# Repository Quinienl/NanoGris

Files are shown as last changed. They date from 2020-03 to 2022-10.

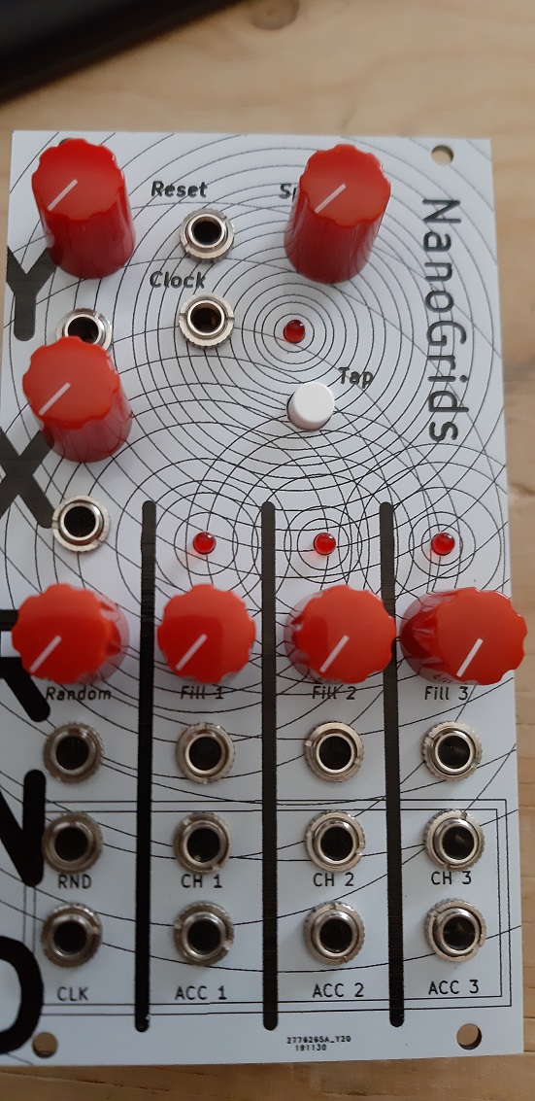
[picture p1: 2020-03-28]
Images/red.jpg

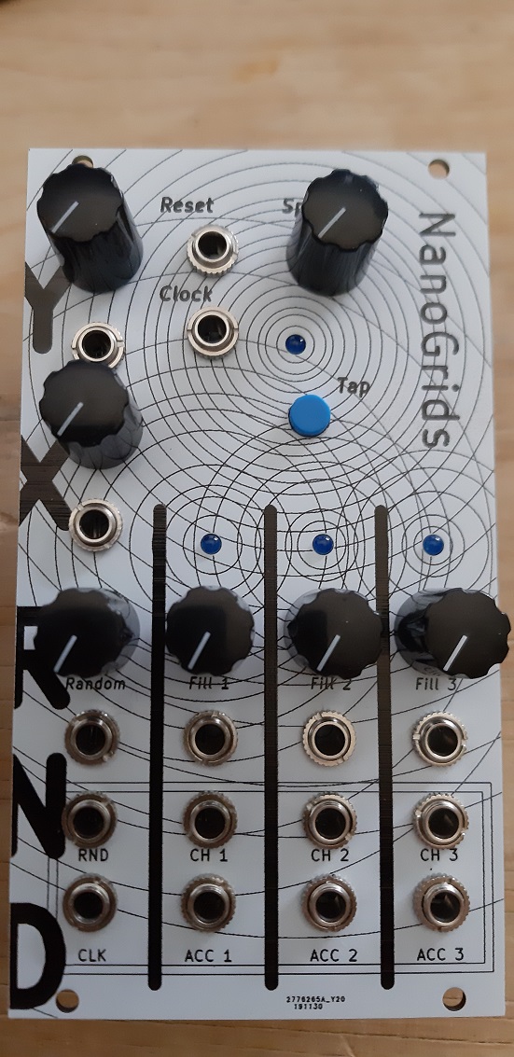
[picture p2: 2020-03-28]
Images/blue.jpg

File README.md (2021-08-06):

# NanoGrids
### Arduino Nano version of Mutable Instruments Grids

Made this version  with Thru Hole parts and a Arduino Nano.
Schematics are heavely based on Mutable Instruments schematics. This is not a Mutable Instuments product.

_Note: panel hole for button might be a bit to big or small (depends if you use buttoncaps)_

I made this for my own and would like to share it with you. I'm doing this as a hobby so expect support to be like that to ;)
Everything at your own risk..

Some info on my website that might help

https://www.quinie.nl/category/diy/nanogris/

https://www.quinie.nl/nanogris-gallery/

If you don not want to order boards yourself please check out my shop.
https://www.quinie.nl/shop/

hex file for uploading here
https://www.quinie.nl/nanogris-the-hex-file/

Update: 6-8-2021
I updated the name of the module. The current version is 0.041

Older boards will have the same function. Did add some better ground planes. Some silkscreen additions to make build easier and changed the footprint of the potentiometer for better fit.

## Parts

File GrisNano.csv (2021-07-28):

Comment | Designator | Footprint | LCSC
Arduino_Nano_v2.x | A1 | Module:Arduino_Nano
10nf | C1,C2,C5,C6,C8,C9,C12 | Capacitor_THT:C_Disc_D5.0mm_W2.5mm_P2.50mm
10uf | C14,C13 | Capacitor_THT:CP_Radial_D5.0mm_P2.50mm
0.47uf | C15,C11 | Capacitor_THT:CP_Radial_D5.0mm_P2.50mm
100nf | C4,C3,C7,C10,C16 | Capacitor_THT:C_Disc_D5.0mm_W2.5mm_P2.50mm
CH1 | CH1 | Connector_Audio:Jack_3.5mm_QingPu_WQP-PJ398SM_Vertical_CircularHoles
CH1_ACC | CH1_AC1 | Connector_Audio:Jack_3.5mm_QingPu_WQP-PJ398SM_Vertical_CircularHoles
CV_CH1 | CH1_FILL1 | Connector_Audio:Jack_3.5mm_QingPu_WQP-PJ398SM_Vertical_CircularHoles
CH2 | CH2 | Connector_Audio:Jack_3.5mm_QingPu_WQP-PJ398SM_Vertical_CircularHoles
CH2_ACC | CH2_AC1 | Connector_Audio:Jack_3.5mm_QingPu_WQP-PJ398SM_Vertical_CircularHoles
CV_CH2 | CH2_FILL1 | Connector_Audio:Jack_3.5mm_QingPu_WQP-PJ398SM_Vertical_CircularHoles
CH3 | CH3 | Connector_Audio:Jack_3.5mm_QingPu_WQP-PJ398SM_Vertical_CircularHoles
CH3_ACC | CH3_AC1 | Connector_Audio:Jack_3.5mm_QingPu_WQP-PJ398SM_Vertical_CircularHoles
CV_CH3 | CH3_FILL1 | Connector_Audio:Jack_3.5mm_QingPu_WQP-PJ398SM_Vertical_CircularHoles
ClockOutput | CLK1 | Connector_Audio:Jack_3.5mm_QingPu_WQP-PJ398SM_Vertical_CircularHoles
CV_CLOCK | CLOCK1 | Connector_Audio:Jack_3.5mm_QingPu_WQP-PJ398SM_Vertical_CircularHoles
CH1 | D1 | LED_THT:LED_D3.0mm
CH2 | D2 | LED_THT:LED_D3.0mm
CH3 | D3 | LED_THT:LED_D3.0mm
CLK | D4 | LED_THT:LED_D3.0mm
1n4148 | D6,D5 | Diode_THT:D_DO-34_SOD68_P7.62mm_Horizontal
Fiducial | FID1 | Symbol:OSHW-Logo2_7.3x6mm_SilkScreen
Fiducial | FID2 | Symbol:OSHW-Logo2_14.6x12mm_SilkScreen
MountingHole | H1,H2 | MountingHole:MountingHole_3.2mm_M3
Conn_01x12 | J10 | Connector_PinSocket_2.54mm:PinSocket_1x12_P2.54mm_Vertical
Conn_01x12 | J11 | Connector_PinHeader_2.54mm:PinHeader_1x12_P2.54mm_Vertical
Conn_02x05_Odd_Even | J12 | Connector_PinHeader_2.54mm:PinHeader_2x05_P2.54mm_Vertical
Conn_01x10 | J14,J15 | Connector_PinHeader_2.54mm:PinHeader_1x10_P2.54mm_Vertical
Conn_01x03 | J16 | Connector_PinHeader_2.54mm:PinHeader_1x03_P2.54mm_Vertical
Conn_01x10 | J7,J13 | Connector_PinSocket_2.54mm:PinSocket_1x10_P2.54mm_Vertical
10k | P_TEMPO1,P_CH2,P_CH1,P_X1,P_CH3,P_RND1,P_Y1 | Potentiometer_THT:Potentiometer_Alpha_RD901F-40-00D_Single_Vertical
2N3904 | Q2,Q1 | Package_TO_SOT_THT:TO-92_Wide
100k | R1,R2,R3,R7,R4,R5,R6,R8,R9,R10,R11,R15,R12,R13,R14,R16,R17,R18,R19,R23,R20,R21,R22,R24,R43,R44,R45,R42,R41,R40,R31 | Resistor_THT:R_Axial_DIN0204_L3.6mm_D1.6mm_P7.62mm_Horizontal
100r | R25,R28,R27,R26 | Resistor_THT:R_Axial_DIN0207_L6.3mm_D2.5mm_P7.62mm_Horizontal
10r | R30,R29 | Resistor_THT:R_Axial_DIN0204_L3.6mm_D1.6mm_P7.62mm_Horizontal
1k | R39,R38,R37,R36,R35,R34,R33,R32 | Resistor_THT:R_Axial_DIN0204_L3.6mm_D1.6mm_P7.62mm_Horizontal
CV_RESET | RESET1 | Connector_Audio:Jack_3.5mm_QingPu_WQP-PJ398SM_Vertical_CircularHoles
SW_Push | RESET2 | Button_Switch_THT:SW_PUSH_6mm
RandomGate | RND1 | Connector_Audio:Jack_3.5mm_QingPu_WQP-PJ398SM_Vertical_CircularHoles
CV_RND | RND2 | Connector_Audio:Jack_3.5mm_QingPu_WQP-PJ398SM_Vertical_CircularHoles
MCP6002_1 | U1,U2,U3 | Package_DIP:DIP-8_W7.62mm
L7805 | U4 | Package_TO_SOT_THT:TO-220-3_Vertical
LM4040LP-5 | U5 | Package_TO_SOT_THT:TO-92_Wide
74HC595 | U6 | Package_DIP:DIP-16_W7.62mm
CV_X | X1 | Connector_Audio:Jack_3.5mm_QingPu_WQP-PJ398SM_Vertical_CircularHoles
CV_Y | Y1 | Connector_Audio:Jack_3.5mm_QingPu_WQP-PJ398SM_Vertical_CircularHoles

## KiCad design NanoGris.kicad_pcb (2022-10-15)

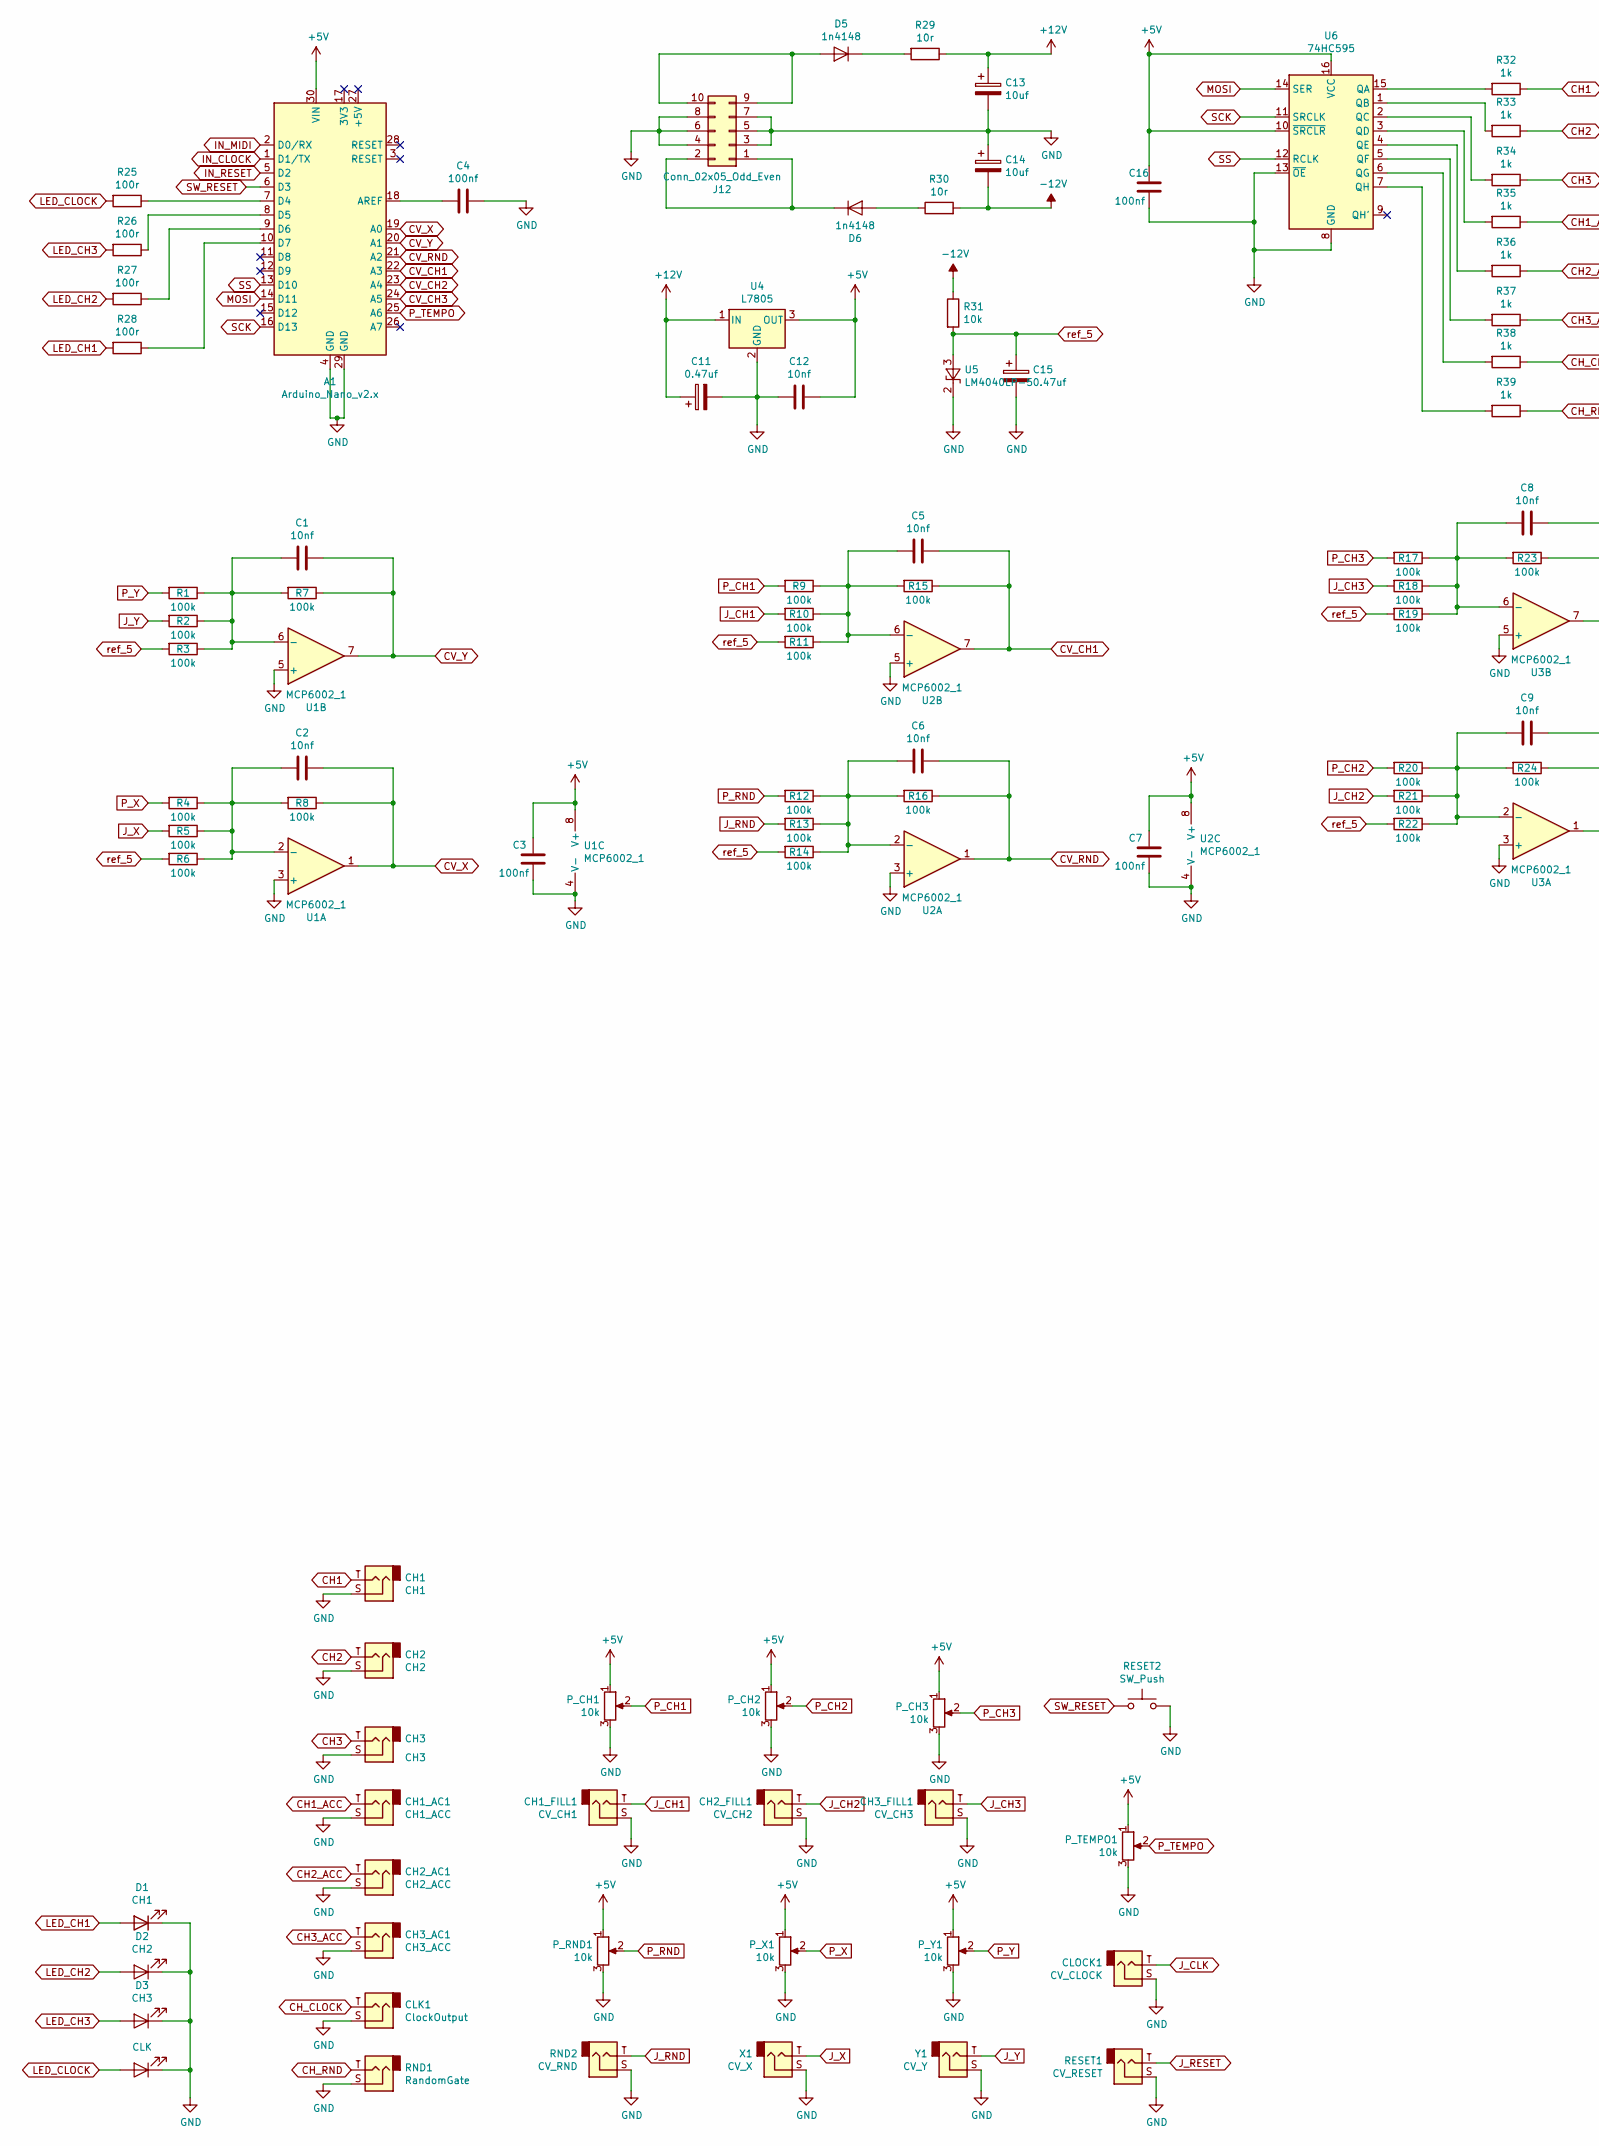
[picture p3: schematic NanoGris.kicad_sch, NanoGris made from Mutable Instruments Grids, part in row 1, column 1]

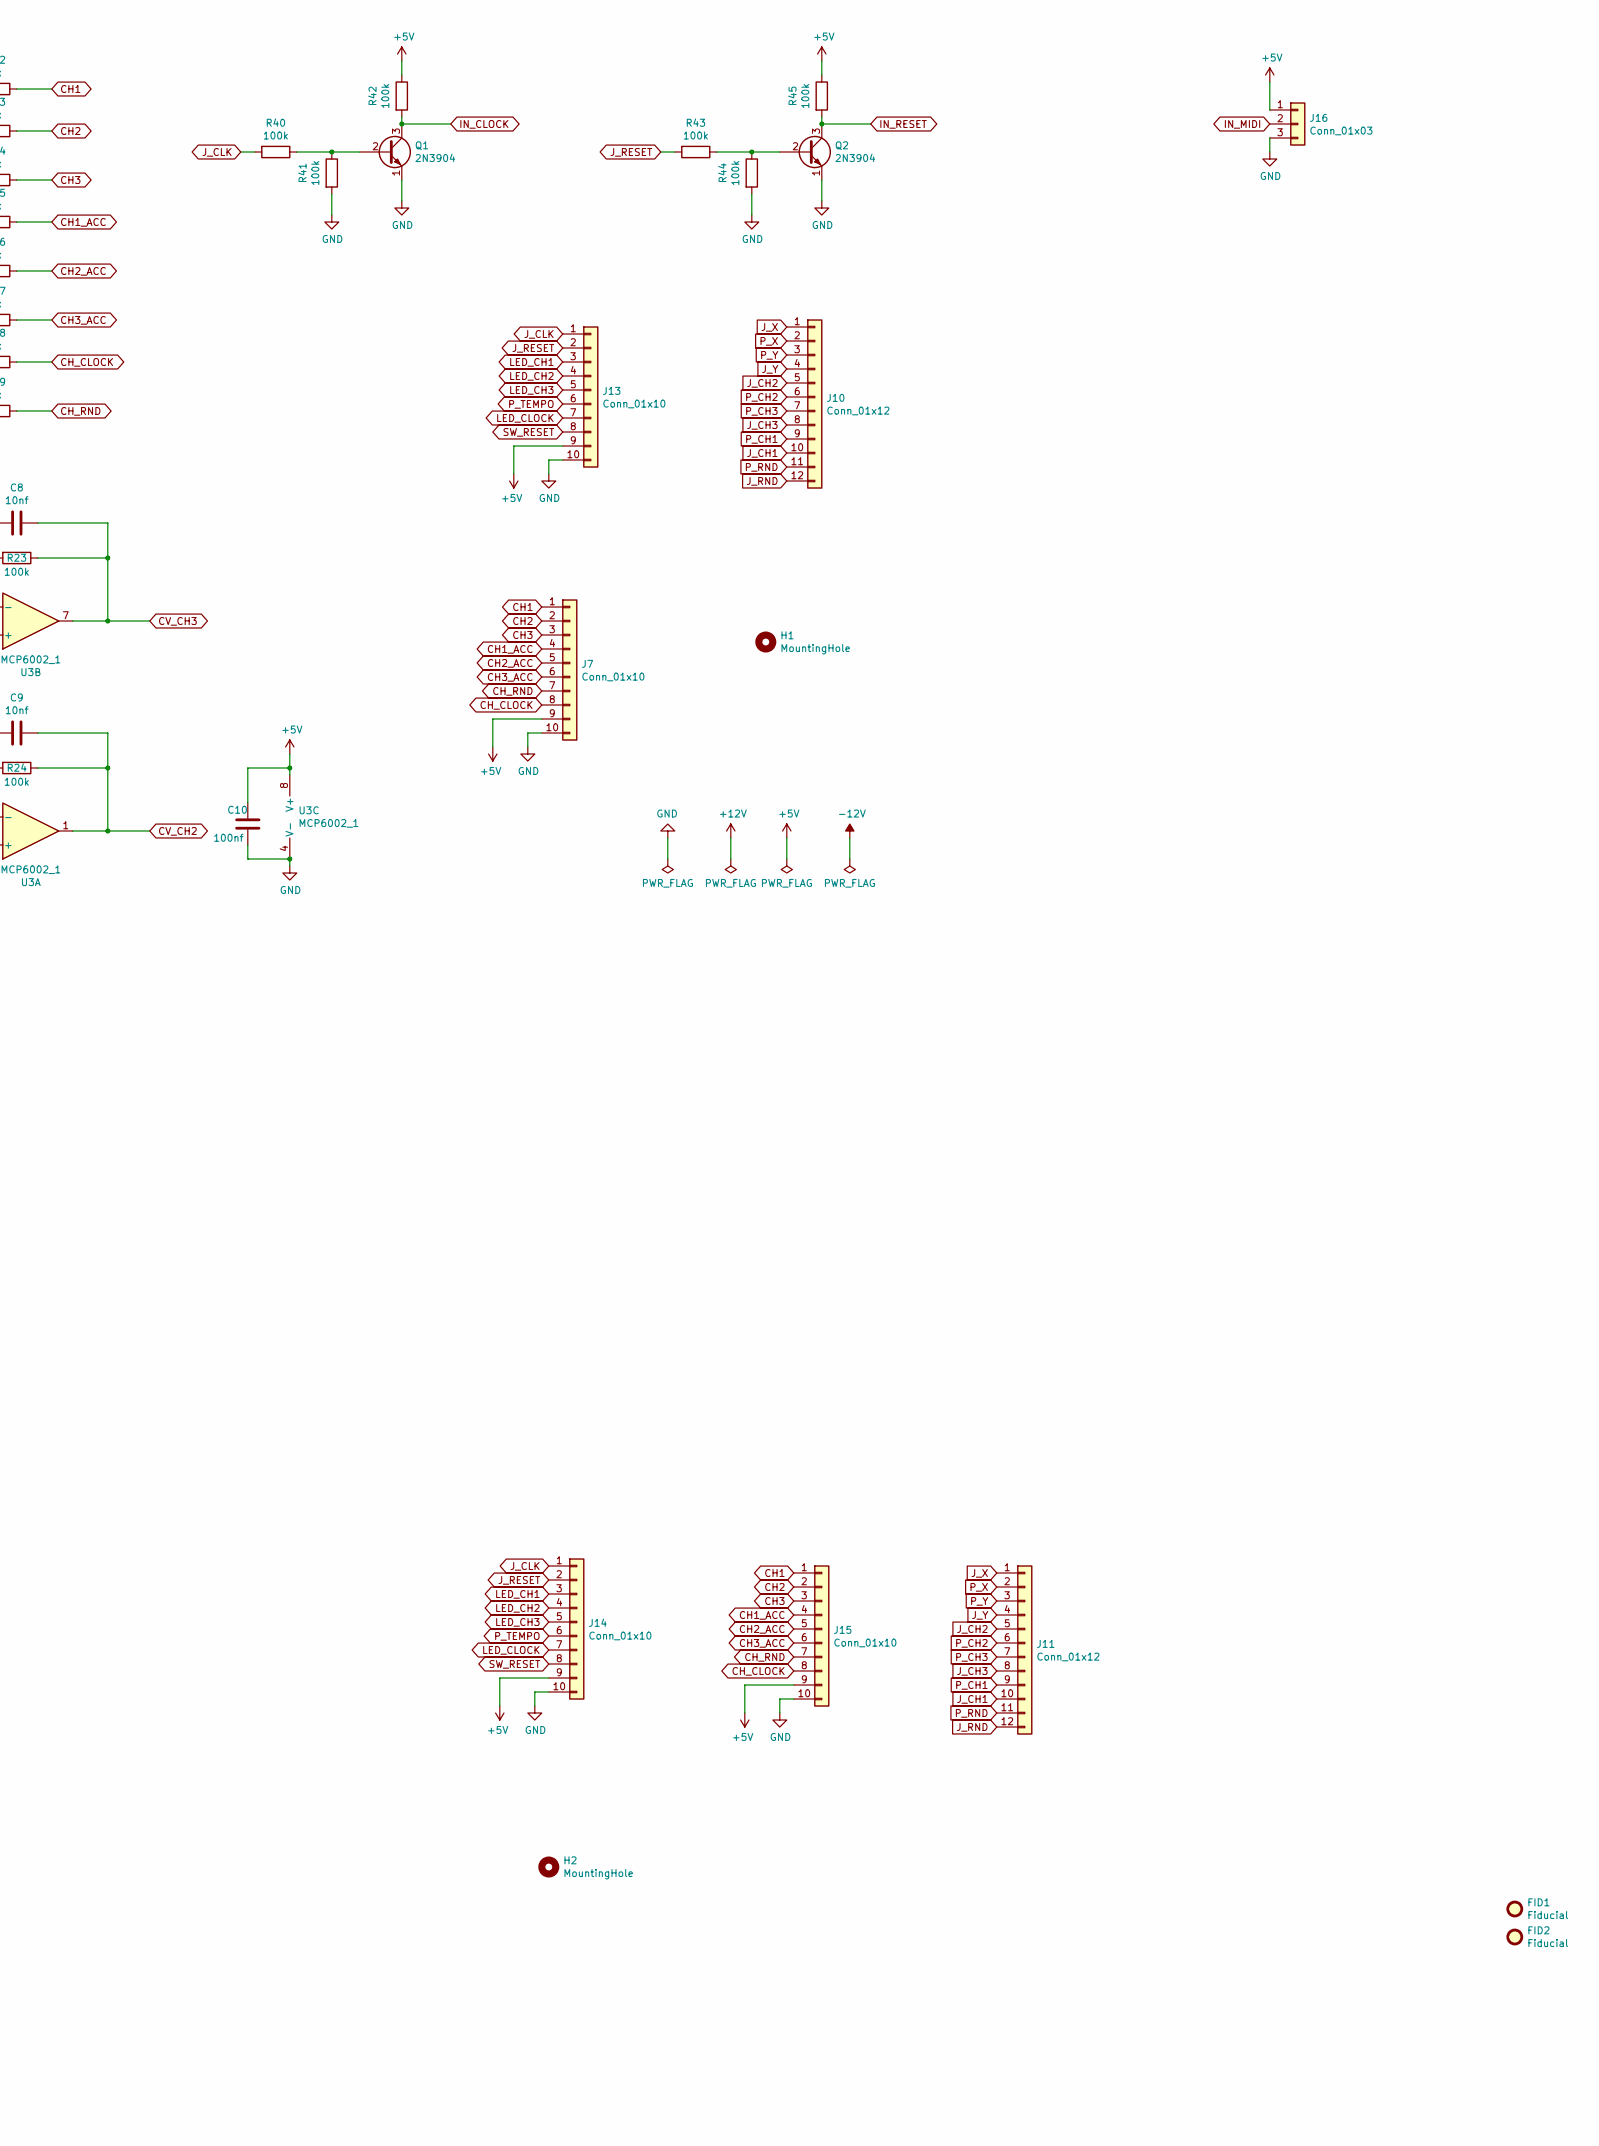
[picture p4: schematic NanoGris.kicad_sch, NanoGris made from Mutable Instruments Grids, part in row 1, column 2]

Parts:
A1: Arduino_Nano_v2.x; Arduino_Nano
C1, C2, C5, C6, C8, C9, C12: 10nf; C_Disc_D5.0mm_W2.5mm_P2.50mm
C3, C4, C7, C10, C16: 100nf; C_Disc_D5.0mm_W2.5mm_P2.50mm
C11, C15: 0.47uf; CP_Radial_D5.0mm_P2.50mm
C13, C14: 10uf; CP_Radial_D5.0mm_P2.50mm
CH1: CH1; Jack_3.5mm_QingPu_WQP-PJ398SM_Vertical_CircularHoles
CH1_AC1: CH1_ACC; Jack_3.5mm_QingPu_WQP-PJ398SM_Vertical_CircularHoles
CH1_FILL1: CV_CH1; Jack_3.5mm_QingPu_WQP-PJ398SM_Vertical_CircularHoles
CH2: CH2; Jack_3.5mm_QingPu_WQP-PJ398SM_Vertical_CircularHoles
CH2_AC1: CH2_ACC; Jack_3.5mm_QingPu_WQP-PJ398SM_Vertical_CircularHoles
CH2_FILL1: CV_CH2; Jack_3.5mm_QingPu_WQP-PJ398SM_Vertical_CircularHoles
CH3: CH3; Jack_3.5mm_QingPu_WQP-PJ398SM_Vertical_CircularHoles
CH3_AC1: CH3_ACC; Jack_3.5mm_QingPu_WQP-PJ398SM_Vertical_CircularHoles
CH3_FILL1: CV_CH3; Jack_3.5mm_QingPu_WQP-PJ398SM_Vertical_CircularHoles
CLK1: ClockOutput; Jack_3.5mm_QingPu_WQP-PJ398SM_Vertical_CircularHoles
CLOCK1: CV_CLOCK; Jack_3.5mm_QingPu_WQP-PJ398SM_Vertical_CircularHoles
D1: CH1; LED_D3.0mm
D2: CH2; LED_D3.0mm
D3: CH3; LED_D3.0mm
D4: CLK; LED_D3.0mm
D5, D6: 1n4148; D_DO-34_SOD68_P7.62mm_Horizontal
FID1: Fiducial; OSHW-Logo2_7.3x6mm_SilkScreen
FID2: Fiducial; OSHW-Logo2_14.6x12mm_SilkScreen
H1, H2: MountingHole; MountingHole_3.2mm_M3
J7, J13: Conn_01x10; PinSocket_1x10_P2.54mm_Vertical
J10: Conn_01x12; PinSocket_1x12_P2.54mm_Vertical
J11: Conn_01x12; PinHeader_1x12_P2.54mm_Vertical
J12: Conn_02x05_Odd_Even; IDC-Header_2x05_P2.54mm_Vertical
J14, J15: Conn_01x10; PinHeader_1x10_P2.54mm_Vertical
J16: Conn_01x03; PinHeader_1x03_P2.54mm_Vertical
P_CH1, P_CH2, P_CH3: 10k; Potentiometer_Alps_RK09K_Single_Vertical_round
P_RND1: 10k; Potentiometer_Alps_RK09K_Single_Vertical_round
P_TEMPO1: 10k; Potentiometer_Alps_RK09K_Single_Vertical_round
P_X1: 10k; Potentiometer_Alps_RK09K_Single_Vertical_round
P_Y1: 10k; Potentiometer_Alps_RK09K_Single_Vertical_round
Q1, Q2: 2N3904; TO-92_Wide
R1, R2, R3, R4, R5, R6, R7, R8, R9, R10, R11, R12, R13, R14, R15, R16, R17, R18, R19, R20, R21, R22, R23, R24, R40, R41, R42, R43, R44, R45: 100k; R_Axial_DIN0204_L3.6mm_D1.6mm_P7.62mm_Horizontal
R25, R26, R27, R28: 100r; R_Axial_DIN0207_L6.3mm_D2.5mm_P7.62mm_Horizontal
R29, R30: 10r; R_Axial_DIN0204_L3.6mm_D1.6mm_P7.62mm_Horizontal
R31: 10k; R_Axial_DIN0204_L3.6mm_D1.6mm_P7.62mm_Horizontal
R32, R33, R34, R35, R36, R37, R38, R39: 1k; R_Axial_DIN0204_L3.6mm_D1.6mm_P7.62mm_Horizontal
RESET1: CV_RESET; Jack_3.5mm_QingPu_WQP-PJ398SM_Vertical_CircularHoles
RESET2: SW_Push; SW_PUSH_6mm
RND1: RandomGate; Jack_3.5mm_QingPu_WQP-PJ398SM_Vertical_CircularHoles
RND2: CV_RND; Jack_3.5mm_QingPu_WQP-PJ398SM_Vertical_CircularHoles
U1, U2, U3: MCP6002_1; DIP-8_W7.62mm
U4: L7805; TO-220-3_Vertical
U5: LM4040LP-5; TO-92_Wide
U6: 74HC595; DIP-16_W7.62mm
X1: CV_X; Jack_3.5mm_QingPu_WQP-PJ398SM_Vertical_CircularHoles
Y1: CV_Y; Jack_3.5mm_QingPu_WQP-PJ398SM_Vertical_CircularHoles

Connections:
+5V: A1.30 (VIN), C3.1, C7.1, C10.1, C12.1, C16.1, J7.9, J13.9, J14.9, J15.9, J16.1, P_CH1.1, P_CH2.1, P_CH3.1, P_RND1.1, P_TEMPO1.1, P_X1.1, P_Y1.1, R42.1, R45.1, U1.8 (V+), U2.8 (V+), U3.8 (V+), U4.3 (OUT), U6.10 (~SRCLR), U6.16 (VCC)
+12V: C11.1, C13.1, R29.1, U4.1 (IN)
-12V: C14.2, R30.2, R31.1
CH1: CH1.T, J7.1, J15.1, R32.1
CH1_ACC: CH1_AC1.T, J7.4, J15.4, R35.1
CH2: CH2.T, J7.2, J15.2, R33.1
CH2_ACC: CH2_AC1.T, J7.5, J15.5, R36.1
CH3: CH3.T, J7.3, J15.3, R34.1
CH3_ACC: CH3_AC1.T, J7.6, J15.6, R37.1
CH_CLOCK: CLK1.T, J7.8, J15.8, R38.1
CH_RND: J7.7, J15.7, R39.1, RND1.T
CV_CH1: A1.22 (A3), C5.1, R15.1, U2.7
CV_CH2: A1.23 (A4), C9.1, R24.1, U3.1
CV_CH3: A1.24 (A5), C8.1, R23.1, U3.7
CV_RND: A1.21 (A2), C6.1, R16.1, U2.1
CV_X: A1.19 (A0), C2.1, R8.1, U1.1
CV_Y: A1.20 (A1), C1.1, R7.1, U1.7
GND: A1.4 (GND), A1.29 (GND), C3.2, C4.1, C7.2, C10.2, C11.2, C12.2, C13.2, C14.1, C15.2, C16.2, CH1.S, CH1_AC1.S, CH1_FILL1.S, CH2.S, CH2_AC1.S, CH2_FILL1.S, CH3.S, CH3_AC1.S, CH3_FILL1.S, CLK1.S, CLOCK1.S, D1.1 (K), D2.1 (K), D3.1 (K), D4.1 (K), J7.10, J12.3, J12.4, J12.5, J12.6, J12.7, J12.8, J13.10, J14.10, J15.10, J16.3, P_CH1.3, P_CH2.3, P_CH3.3, P_RND1.3, P_TEMPO1.3, P_X1.3, P_Y1.3, Q1.1 (E), Q2.1 (E), R41.2, R44.2, RESET1.S, RESET2.2, RND1.S, RND2.S, U1.3 (+), U1.4 (V-), U1.5 (+), U2.3 (+), U2.4 (V-), U2.5 (+), U3.3 (+), U3.4 (V-), U3.5 (+), U4.2 (GND), U5.2 (K), U6.8 (GND), U6.13 (~OE), X1.S, Y1.S
IN_CLOCK: A1.1 (D1/TX), Q1.3 (C), R42.2
IN_MIDI: A1.2 (D0/RX), J16.2
IN_RESET: A1.5 (D2), Q2.3 (C), R45.2
J_CH1: CH1_FILL1.T, J10.10, J11.10, R10.2
J_CH2: CH2_FILL1.T, J10.5, J11.5, R21.2
J_CH3: CH3_FILL1.T, J10.8, J11.8, R18.2
J_CLK: CLOCK1.T, J13.1, J14.1, R40.2
J_RESET: J13.2, J14.2, R43.2, RESET1.T
J_RND: J10.12, J11.12, R13.2, RND2.T
J_X: J10.1, J11.1, R5.2, X1.T
J_Y: J10.4, J11.4, R2.2, Y1.T
LED_CH1: D1.2 (A), J13.3, J14.3, R28.2
LED_CH2: D2.2 (A), J13.4, J14.4, R27.2
LED_CH3: D3.2 (A), J13.5, J14.5, R26.2
LED_CLOCK: D4.2 (A), J13.7, J14.7, R25.2
MOSI: A1.14 (D11), U6.14 (SER)
unnamed: A1.7 (D4), R25.1
unnamed: A1.8 (D5), R26.1
unnamed: A1.9 (D6), R27.1
unnamed: A1.10 (D7), R28.1
unnamed: A1.18 (AREF), C4.2
unnamed: C1.2, R1.1, R2.1, R3.1, R7.2, U1.6 (-)
unnamed: C2.2, R4.1, R5.1, R6.1, R8.2, U1.2 (-)
unnamed: C5.2, R9.1, R10.1, R11.1, R15.2, U2.6 (-)
unnamed: C6.2, R12.1, R13.1, R14.1, R16.2, U2.2 (-)
unnamed: C8.2, R17.1, R18.1, R19.1, R23.2, U3.6 (-)
unnamed: C9.2, R20.1, R21.1, R22.1, R24.2, U3.2 (-)
unnamed: D5.1 (K), R29.2
unnamed: D5.2 (A), J12.9, J12.10
unnamed: D6.1 (K), J12.1, J12.2
unnamed: D6.2 (A), R30.1
unnamed: Q1.2 (B), R40.1, R41.1
unnamed: Q2.2 (B), R43.1, R44.1
unnamed: R32.2, U6.15 (QA)
unnamed: R33.2, U6.1 (QB)
unnamed: R34.2, U6.2 (QC)
unnamed: R35.2, U6.3 (QD)
unnamed: R36.2, U6.4 (QE)
unnamed: R37.2, U6.5 (QF)
unnamed: R38.2, U6.6 (QG)
unnamed: R39.2, U6.7 (QH)
P_CH1: J10.9, J11.9, P_CH1.2, R9.2
P_CH2: J10.6, J11.6, P_CH2.2, R20.2
P_CH3: J10.7, J11.7, P_CH3.2, R17.2
P_RND: J10.11, J11.11, P_RND1.2, R12.2
P_TEMPO: A1.25 (A6), J13.6, J14.6, P_TEMPO1.2
P_X: J10.2, J11.2, P_X1.2, R4.2
P_Y: J10.3, J11.3, P_Y1.2, R1.2
SCK: A1.16 (D13), U6.11 (SRCLK)
SS: A1.13 (D10), U6.12 (RCLK)
SW_RESET: A1.6 (D3), J13.8, J14.8, RESET2.1
ref_5: C15.1, R3.2, R6.2, R11.2, R14.2, R19.2, R22.2, R31.2, U5.3 (A)

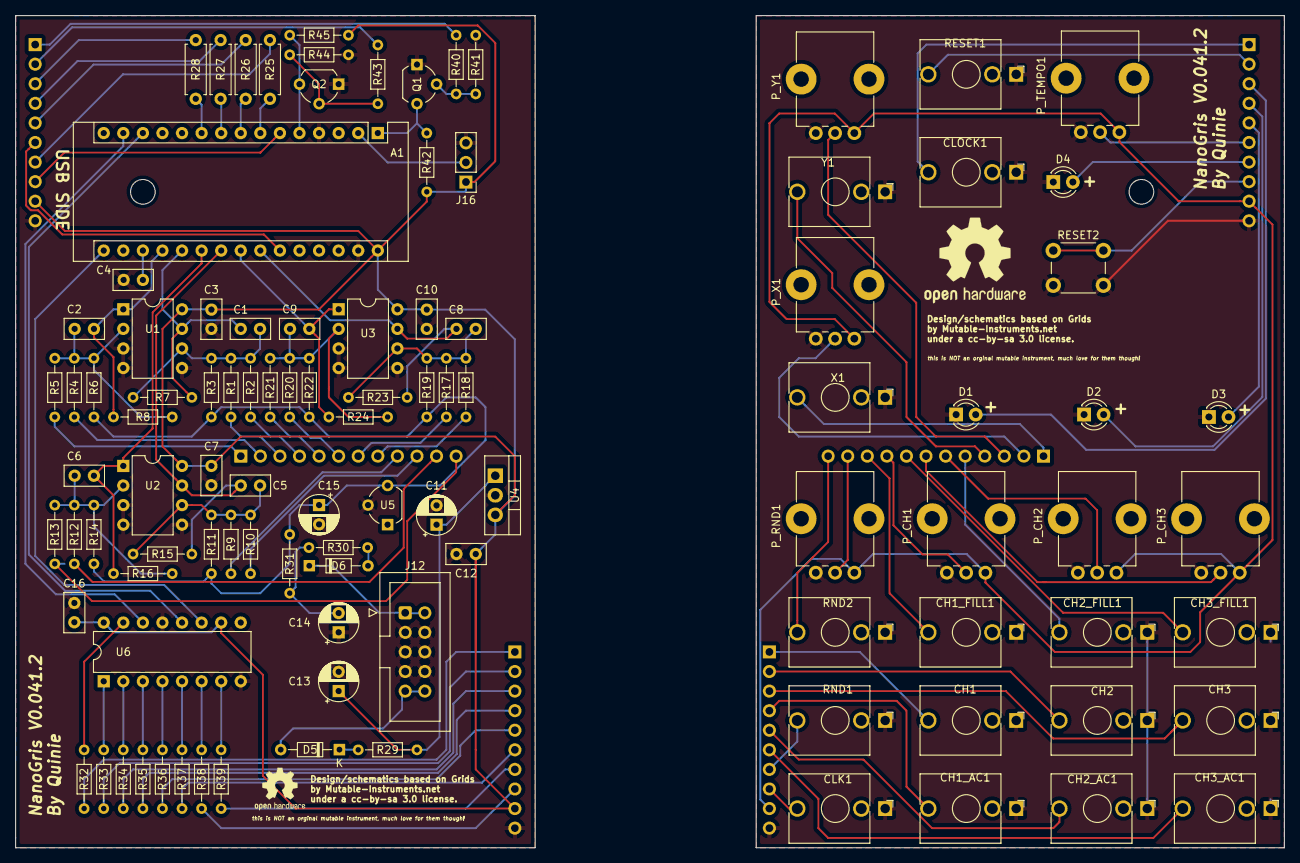
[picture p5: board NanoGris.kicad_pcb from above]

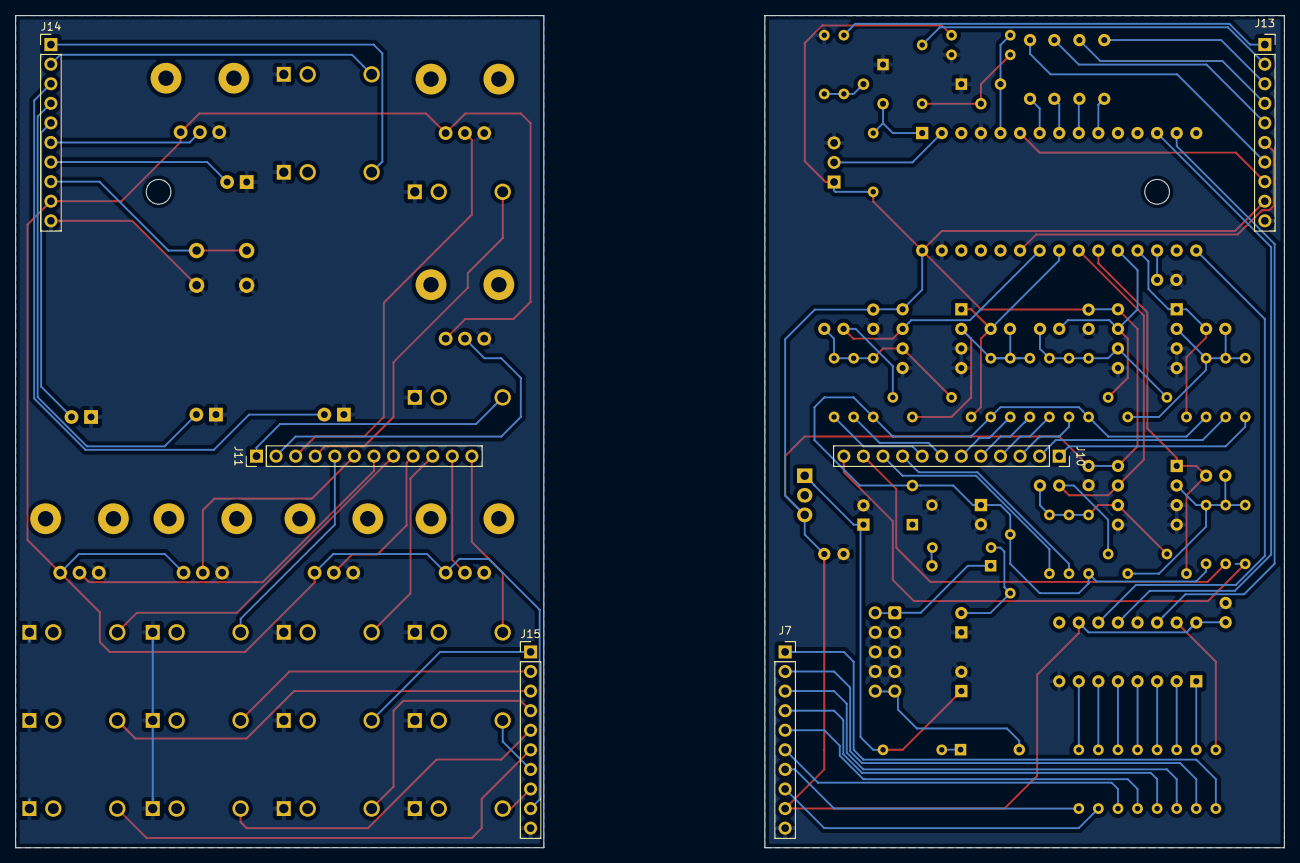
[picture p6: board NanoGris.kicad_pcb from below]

Board: 2 copper layers, 164.6 x 108.0 mm, 112 parts (6 on the bottom side), 70 nets.

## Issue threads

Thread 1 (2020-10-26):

Is there a BOM?

angiamusic, 2020-10-26:
Hello,

I'm interested in making one of these myself, however I wasn't able to find the BOM. Would you happen to be able to provide one? Or is there already one and I'm just missing something?

Thank you!

Quinienl, 2020-10-26:
Hi there,

There is a topic on muffwiggel about this module. The Bom should be in the kicad project. Kicad should be able to export this.
If you can not find the option or have trouble with it please let me know and I will send you the BOM.

Keep in mind I'm no where a real electonics engineer. so some minor mistakes could be made.
Also see the muffwiggle topic. Someone was able to build it without to much trouble.

I even think I got some of his trouble fixed before uploading it to git.

Best regards
Quinie

On Maandag 26 Oktober 2020 14:51 CET, angiamusic <notifications@github.com> wrote:
 
 
Hello,
I'm interested in making one of these myself, however I wasn't able to find the BOM. Would you happen to be able to provide one? Or is there already one and I'm just missing something?
Thank you!
—
You are receiving this because you are subscribed to this thread.
Reply to this email directly, view it on GitHub, or unsubscribe.
 

angiamusic, 2020-10-26:
Thank you for your quick reply! I was successfully able to get the BOM from the Kicad itself, still only just learning so I didn't know that was possible haha.

Regards,
Aditya

Quinienl, 2020-10-26:
Put some extra info on my website. BOM also ;)
http://www.quinie.nl/?p=17

Closed 2020-10-26.

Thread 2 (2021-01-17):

.ino file?

strpstv, 2021-01-17:
Hi! i'm cuilding your nanogrids at the moment and was wonderint how you flashed the program to the microprocessor? Can't seem to find any file to load on it? thank you!

Phipanjo, 2021-03-10:
Hi, same problem here :S Really nice module; I read on your homepage you may have some panels / PCBs at stock. May you send me one set? Of course I will pay for that :-)

strpstv, 2021-03-11:
hey phipanjo, i succeeded mine.
You need to uplad this hex file to the nano: drive.google.com/drive/folders/0B5t7I7Q0p5bpdVEwamdscjJvdVU
i used this technique to prepare my chinese nano (but there are other ways): https://support.arduino.cc/hc/en-us/articles/360012048100-How-to-burn-the-bootloader-in-an-Arduino-Nano-using-an-Arduino-UNO
and then used this software to program the hex on it: https://www.polaxis.be/download/easyuploader-for-mac/

Quinienl, 2021-03-11:
You can use the code by Mutable Instrument. But then you have to make your own .hex and upload it to the nano. I have not tested the hex strpstv has posted, but I did upload a hex file to my site.

https://www.quinie.nl/nanogrids-the-hex-file/

For board I still have a few left and selling these at 15 euro's the set (panel and 2 pcb's). I have a few black and white panels remaining. You can contact me on the contact form (quinie.nl) or just email me at Qui...@Quinie.nl.

Phipanjo, 2021-03-12:
Perfect guys, thank you!
I will order a kit these days; you'll get mail :-D

Closed 2021-05-21.

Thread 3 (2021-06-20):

Confused about the Arduino nano version

sewtsPatrick, 2021-06-20:
The BOM on the website says nano v2.x but the filenames say gridsNanoV3. Will the files on master work für nano v3 and if not can I swap the pins anywhere in software (since nano v2 and v3 have swapped addresses for analog pins AFAIK)?

Quinienl, 2021-06-22:
Hi sorry for the confusion. I think i used the footprint of a nano 2 in the software or something like that have to double check.
But you should install a Nano v3.

I also have seen a version with a seeeduino

_Quote from other builder Erik: I used the new cheaper seeeduino nano. Working perfectly!_

sewtsPatrick, 2021-06-23:
@Quinienl thank you very much for your quick response and the awesome design! Can't wait to build mine :)

Closed 2021-06-23.

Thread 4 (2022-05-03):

old gerber version and current firmware

sewtsPatrick, 2022-05-03:
Hi Quinie,

I've built a version of your module a while back (pcbs version 3) and it seemed to work fine.
Now, with the same PCBs I had left over, I built two more, but they seem to be both having the same issue (which makes me think its software related):
Generally it works, but the accent outputs are always mapped to the alternative mode (where it outputs the clock and not the individual accents). When i hold down the settings button I can get into the settings menu, but changing the pots does not correctly update the settings the way it should from what I've seen in mutable tutorials.

Has there been a change in pinout or something that causes mismatch with old PCBs when using the current version of the firmware (found on your blog page)?

Quinienl, 2022-05-13:
Hi Patrick,

sorry for the late responds. I have been a bit offline. I had some troubles with my health but it's getting better.

I had a email from someone a few weeks ago about a resistor value that is differently from th MI orginal.
I haven't check it but it is related to the pots. I believe it's R34 but still have to dive into it.

This would cause the pot's not having there full range. You can test it by using a external voltage on the inputs.
This might help you out reaching the correct settings.

When my health is a little better and when I'm up for it I will dive into this myself.

Greets Quinie

On Dinsdag 3 Mei 2022 15:21 CEST, sewtsPatrick ***@***.***> wrote:
 
 
Hi Quinie,
I've built a version of your module a while back (pcbs version 3) and it seemed to work fine.
Now, with the same PCBs I had left over, I built two more, but they seem to be both having the same issue (which makes me think its software related):
Generally it works, but the accent outputs are always mapped to the alternative mode (where it outputs the clock and not the individual accents). When i hold down the settings button I can get into the settings menu, but changing the pots does not correctly update the settings the way it should from what I've seen in mutable tutorials.
Has there been a change in pinout or something that causes mismatch with old PCBs when using the current version of the firmware (found on your blog page)?
—
Reply to this email directly, view it on GitHub, or unsubscribe.
You are receiving this because you are subscribed to this thread.Message ID: ***@***.***>

Quinienl, 2022-05-20:
Hi Patrick,

As for you troubles with Nanogrids,

https://www.quinie.nl/nanogris-big-bom-mistake-update-for-better-range-on-pots/
replace R31 to a 10k value.

Hope this will help
Greets Quinie

On Dinsdag 3 Mei 2022 15:21 CEST, sewtsPatrick ***@***.***> wrote:
 
 
Hi Quinie,
I've built a version of your module a while back (pcbs version 3) and it seemed to work fine.
Now, with the same PCBs I had left over, I built two more, but they seem to be both having the same issue (which makes me think its software related):
Generally it works, but the accent outputs are always mapped to the alternative mode (where it outputs the clock and not the individual accents). When i hold down the settings button I can get into the settings menu, but changing the pots does not correctly update the settings the way it should from what I've seen in mutable tutorials.
Has there been a change in pinout or something that causes mismatch with old PCBs when using the current version of the firmware (found on your blog page)?
—
Reply to this email directly, view it on GitHub, or unsubscribe.
You are receiving this because you are subscribed to this thread.Message ID: ***@***.***>

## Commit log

2021-06-26 Updates 0.04
    Updates for 0.04
    Change footprint for pots
    Added + sign for leds
    Added usb side
    Added Ground plane
    [GridsNanoV3.kicad_pcb, GridsNanoV3.sch]
2021-06-26 Panel
    Bigger holes for pots
    [Panel.kicad_pcb, Panel.sch]
2021-06-26 0.04 Commit
    Gerbers
    [GridsNanoV3-B_Cu.gbr, GridsNanoV3-B_Mask.gbr, GridsNanoV3-B_Paste.gbr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]
2021-06-27 Panel Gerbers
    Panel Gerbers 0.04
    [Panel-B_Cu.gbr, Panel-B_Mask.gbr, Panel-B_Paste.gbr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]
2021-07-28 Panel update + IBOM
    missing mounting holes fixed
    Ibom added
    [GridsNanoV3.csv, Panel Clean.kicad_pcb]
2021-07-28 Gerbers and small update
    Panel Gerber and fixed some holes
    [Panel Clean.kicad_pcb, Panel.kicad_pcb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]
2021-07-28 Circular panel gerbers
    [Panel-B_Cu.gbr, Panel-B_Mask.gbr, Panel-B_Paste.gbr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]
2021-07-29 Gerber Update
    [GridsNanoV3-B_Cu.gbr, GridsNanoV3-B_Mask.gbr, GridsNanoV3-B_Paste.gbr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]
2021-08-23 Ibom name update
    [NanoGris.sch]
2022-05-20 Bom Update (R31 needs to be 10K)
    Error inBOM R31 needs to be 10k
    https://www.quinie.nl/nanogris-big-bom-mistake-update-for-better-range-on-pots/
    [NanoGris.kicad_pcb, NanoGris.kicad_sch]
2022-10-15 Updated powerheader
    Now with correct power schematic and boxed header.
    [NanoGris.kicad_pcb, NanoGris.kicad_sch]

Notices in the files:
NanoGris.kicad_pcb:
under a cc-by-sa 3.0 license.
